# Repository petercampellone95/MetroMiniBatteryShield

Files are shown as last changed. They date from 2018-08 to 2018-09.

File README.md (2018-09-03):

# Metro Mini Battery Shield

## Summary
The Metro Mini Battery shield was designed as part of an introductory PCB design course with the primary goal of being the power source and power platform for several other shields (I.E. physically identical "daugther" boards) that would plug into it. 

The battery shield was designed with the following requirements/features in mind:

- Be able to supply approximately 1A of continuous current in order to power Metro Mini and up to three other “daughter” boards simultaneously
- Be able to charge an externally connected LiPo battery and still power the Metro Mini and up to three other “daughter” boards simultaneously
- Be able to take power in from either an external source or from the USB cable connected to the Metro Mini board
- Be able to switch between USB power and battery power automatically in the case that either one is not available
- Be able to measure current draw using a built-in current sense resistor
- Be able to set the charge rate in order to select different charge rates based on different power inputs (USB or external)
- Feature an On/Off switch in order to disable the charger completely if necessary
- The fuel gauge needs to be able to report battery statistics to the Metro Mini over I2C at a regular interval such that the tri-color LED can be used as a visual indication of the “fuel” level of the battery
- Feature a built-in 5V step-up regulator that can take a wide range of input voltage and output a constant 5V (primarily used for stepping up LiPo 3.7V to 5V)

The entire board was designed using Altium Circuitmaker which is a free,stripped down version of Altium Designer. While limited, the software was more than capable for our requirements.
After the design stage was completed the Gerber design files were sent to OSH Park where three copies of our board were fabricated along with a stencil from OSH Stencils. From here we assembled one complete board and began our testing the results of which you can find more about in the final project report. Overall though, the board operated as expected with only some minor design changes needed.

*Please see the ELE391 Final Project report for more specific technical details*

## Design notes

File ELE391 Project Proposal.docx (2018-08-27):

ELE 391 Project Proposal

Peter Campellone, Zackery Duclos, Cole Wright

2/8/2018

Project Focus: LiPo Battery Charger and Fuel Gauge with external battery connection

Project Summary: The overall goal of this project is to create a circuit capable of powering all four daughter-boards as well as the Metro Mini itself. Due to the size of the PCB being constrained to 1.7” x 0.7” we will not be able to integrate a battery into the PCB itself and instead will connect a LiPo battery externally using a JST connector. In order to charge the battery, we will be using a LiPO specific battery charger which also integrates some useful power management features. The primary concern that we previously faced was how to switch between USB charging, USB power, or battery power. The specific power management IC that we chose is able to automatically switch between these based on some parameters that we will later set. Now, in order to measure the remaining capacity of the battery we will be using a LiPO fuel gauge IC which is specifically designed to measure and report the status of a LiPO battery. This is advantageous to directly measuring the battery voltage and setting up a scale based on maximum and minimum values because LiPo battery voltages (at load) are not entirely linear curves. This fuel gauge IC communicates through I2C and by default will switch on an LED at a point where the LiPo battery is about to “die”. By adding some code to the provided code examples we will be able to have the fuel gauge IC switch on some LEDs to indicate different states in the charge/voltage level of the battery. Instead of being limited to exclusively when the battery is about to “die” we can also report when the battery is at optimal voltage levels and when the battery is below optimal levels but still providing power as expected.

In general, we expect to be able to produce a schematic and PCB with these capabilities and functions by the due date. More details about the specific parts and general function of the system can be found in the attached files.

Min Reqs:

-1700 x 700 mils x 62 mils thick

-80 mil radius rounded corners

-4 non-plated mounting holes, 75x75 mils from corners, 2.2mm dia, 0.125” standoff on each

-Pinout to match metro mini

-Envelope:

-0.400” stacking height

-0.280” top clearance

-0.100” bottom clearance

-Battery board output, VIN (6V+) (Current req. TBD per system)

-Current sense resistor on power rails (shunts) on bottom of board: CSR1206FTR100

-50 mil round test points (on bottom of board)

-Fiducial on tope side, 1mm pad, 0.5mm SM exp

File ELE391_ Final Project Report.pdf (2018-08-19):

## ELE391: Final Project Report - Metro Mini Battery Shield

### By: Peter Campellone, Zack Duclos, Cole Wright May 3, 2018

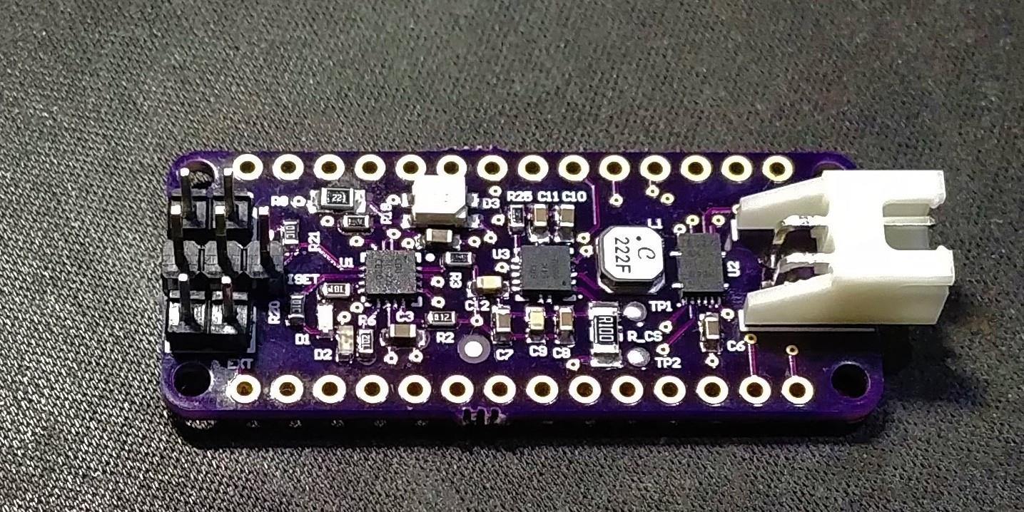
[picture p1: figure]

### Board Requirements

- Be able to supply approximately 1A of continuous current in order to power Metro Mini and up to three other “daughter” boards
- Be able to charge an externally connected LiPo battery
- Be able to charge an externally connected LiPo battery and still power the Metro Mini and up to three other “daughter” boards all at the same time
- Be able to take power in from either an external source or from the USB cable connected to the Metro Mini board
- Be able to switch between USB power and battery power automatically in the case that either one is not available
- Be able to measure current draw using a built-in current sense resistor
- Be able to set the charge rate in order to select different charge rates based on different power inputs (USB, external ,etc)
- Feature an On/Off switch in order to disable the charger completely if necessary
- The fuel gauge needs to be able to report battery statistics to the Metro Mini over I2C at a regular interval such that the tri-color LED can be used as a visual indication of the “fuel” level of the battery
- Feature an built-in 5V step-up regulator that can take a wide range of input voltage and output a constant 5V (primarily used for stepping up LiPo 3.7V to 5V)

### Implementation

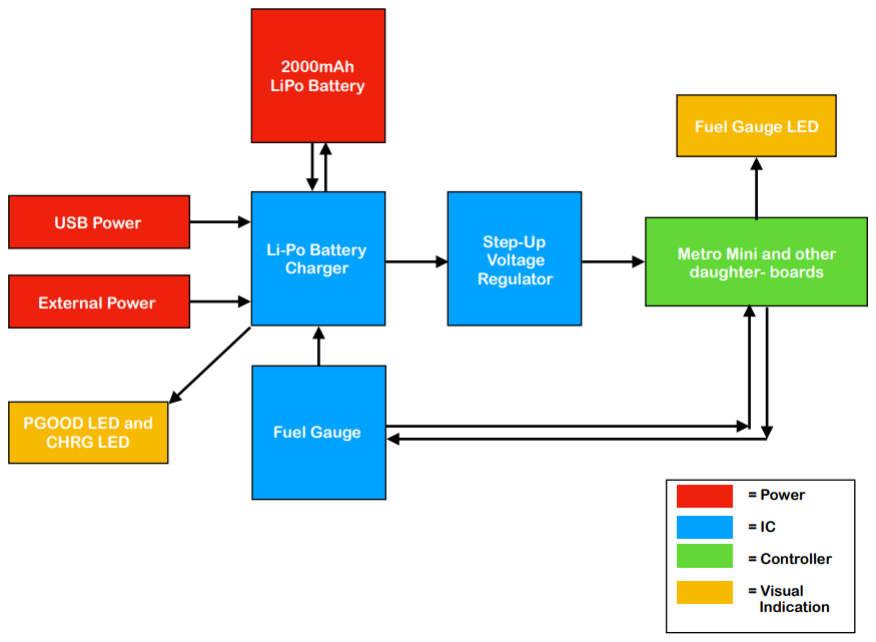
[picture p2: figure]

### The flowchart above displays the connections of the Metro Mini Battery Shield and how the different components interface with one another. The operation is described below:

### 1. Input power is either supplied by the USB connection on the Metro Mini or by an external power connection on the Battery Shield 2. From here the battery charger will direct that power depending on whether or not

a battery is connected.

a. If a battery IS connected then the battery charger will charge that battery and power the Metro Mini simultaneously using a built-in Texas Instruments feature called “Dynamic Power Path Management” b. If a battery IS NOT connected then the battery charger will directly route that power to the Metro Mini 3. Some considerations relevant to the charge and power management processes: a. The battery charger is only enabled when the PWR jumper is shorted b. External power input allowable range is 4.35 - 6.4V c. The ISET jumper defines the charge rate of the battery and connecting the jumper according to the table and image below will define the charge rate

Pin 1 | Pin 2 (GND) | Pin 3 | Charge Mode
Shorted | Shorted | Shorted | 100mA
Shorted | Shorted | Open | 500mA
Open | Shorted | Shorted | 972mA (max based on voltage regulator)
Open | Open | Open | Standby (default)

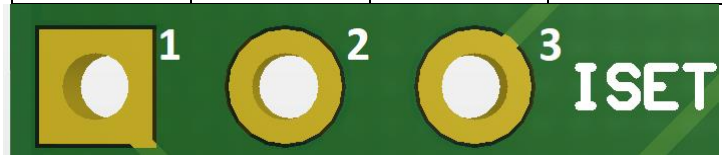
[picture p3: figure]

4. If the battery charging process is started and proceeding successfully then the CHRG LED will illuminate 5. If a battery is connected correctly and the battery charger has recognized it then the PGOOD LED will illuminate 6. The power that passes through the battery charger is sent to the Step-Up voltage regulator in order to output a constant +5V for use by the Metro Mini and other daughter boards. All power will be sent through the step-up regulator regardless

of the power input type or whether or not a battery is connected.

### 7. While all of this is happening the fuel gauge will directly measure the battery and multiple statistics relevant to the battery. These statistics are sent back to the Metro Mini over I2C using Arduino code that was written specifically to be used to

interface with the BQ27441 fuel gauge.

### 8. Part of the Arduino code will drive one of the LEDs on the tri-color LED based on the charge percentage of the battery (a.k.a. State of charge). The color of the LED is based on the following table and state of charge value:

State of Charge | LED Color
Less than 30% (inclusive) | Red
Between 30% and 70% | Yellow
Greater than 70% (inclusive) | Green

### Testing Performed

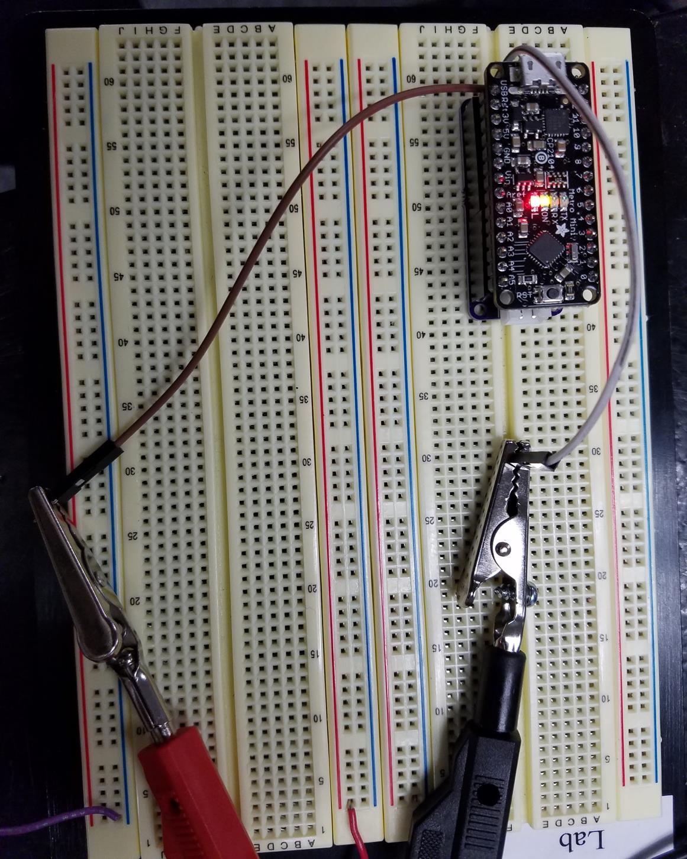
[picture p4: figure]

Figure 1: Testing PCB with external power input, successfully powering Metro Mini

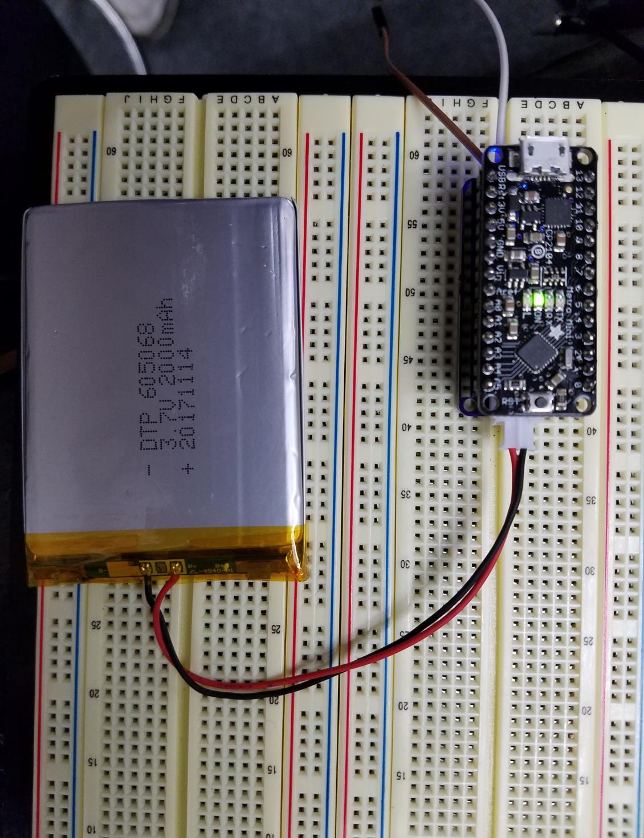
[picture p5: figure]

Figure 2: Testing PCB with battery power, successfully powering Metro Mini, PGOOD LED illuminated indicated battery is recognized by battery charger

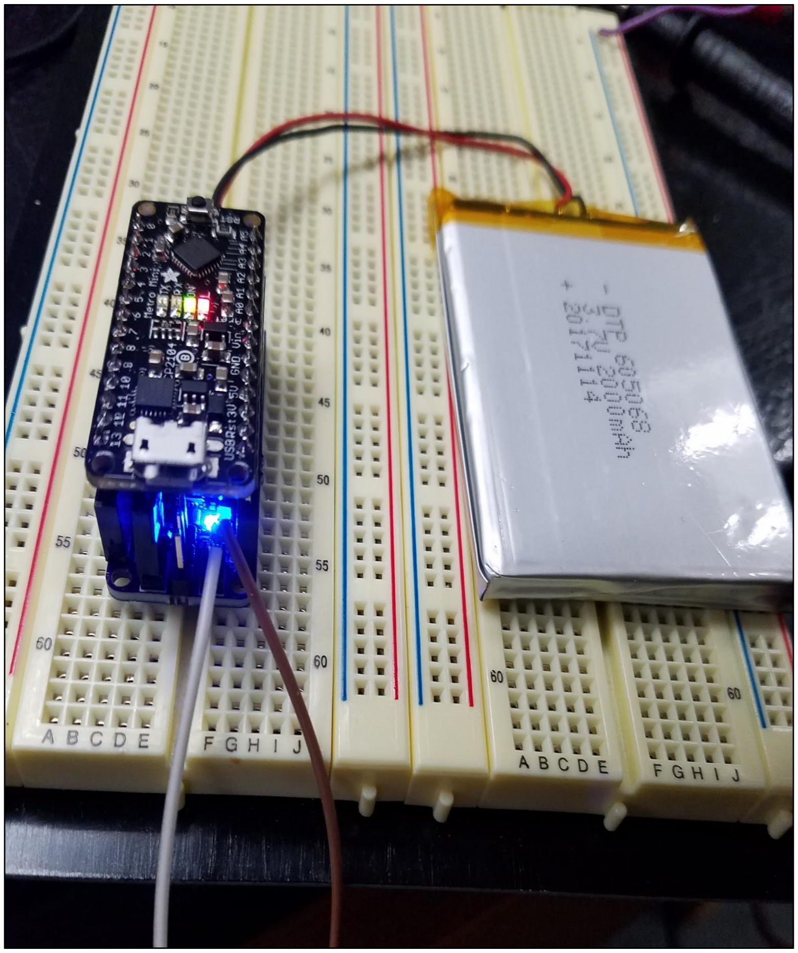
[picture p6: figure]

Figure 3: Testing PCB with battery power, successfully powering Metro Mini, PGOOD LED illuminated indicating that battery charger has recognized battery

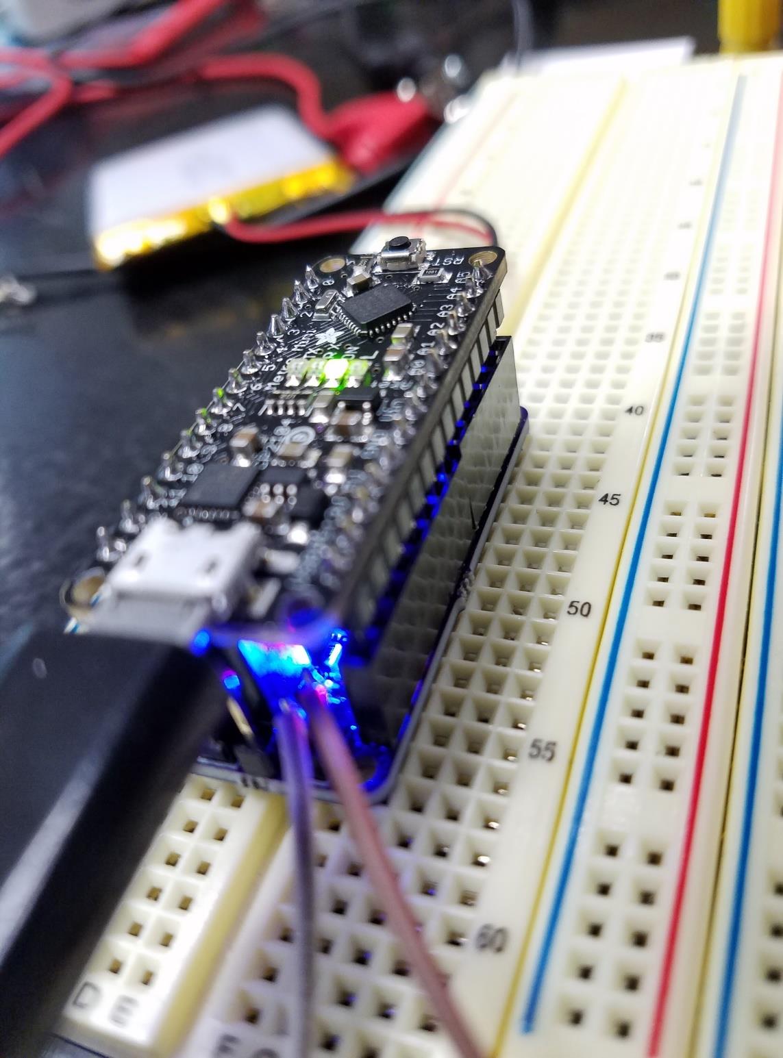
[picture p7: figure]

Figure 4: Testing PCB with USB connection, successfully powering Metro Mini, PGOOD LED illuminated indicating that battery charger has recognized battery, CHRG LED illuminated indicating that battery is being charged using USB power

*In each test, the PCB was tested with all four of the charge rate settings to verify operation and expected current draw*

### Conclusion

In reference to the board requirements listed above only one part of the entire PCB did not work. Specifically, the tri-color LED used as a visual indication of the fuel level did not work after assembly. After examining the PCB, schematics, and datasheet it was determined that the tri-color LED was
common anode although it had been connected as if it was common cathode. This caused the LED to be reversed bias and therefore not illuminate. In order to fix this the ground connection to the common anode pin on the LED needed to be replaced with a connection to the +5V rail. Further, the initial design featured three digital pins on the Metro Mini’s Atmega328 to be used in order to source current to power each of the individual LEDs although with the incorrect common anode connection driving current from the digital pins would not complete the circuit. After our initial testing we tried cutting a trace to ground from the resistor in the tri-color LED circuit and then wiring in a jumper wire to a 5V bus in order to source current through the digital pins for each LED to complete the circuit. While this did work, the solution was not ideal and the modifications were revered to normal in order prevent the PCB from becoming non-functional or damaged.

Regardless of this non-functioning part of the circuit, the rest of the PCB did function as expected. The PCB did meet all of the other board requirements as mentioned above. Although, there were a number of errors noticed and subsequent solutions that could be made in a second revision of the board. These errors and their corresponding solutions are listed below:

### Error/Solution Log

Error: Tri-Color LED wired as common cathode instead of common anode.
Solution: Replace GND connection to tri-color LED anode with +5V bus connection

Error: Jumpers for PWR, EXT, and ISET are difficult to access when Metro Mini is installed on top Solution: Replace Jumpers with right angle connectors or something easily accessible from side or bottom

Error: CHG and PGOOD LED silkscreens are reversed
Solution: Change net labels in schematic

Error: Adjust resistor value for PGOOD LED
Solution: Re-calculate resistor value for PGOOD LED (red) or replace with a different color LED to have comparable brightness to CHRG (blue) LED

Error: Resistor value on tri-color LED is too large and LED brightness is too low
Solution: Replace with a new resistor, recalculate optimal value (likely 100-120 ohm)

Error: JST Connector is wrong physical size, pins are too big for battery connector
Solution: Replace JST connector with correct female part to match physical size and pin size of male JST battery connector

Error: JST connector does not sit flat on PCB and is easily bent when inserting battery connector
Solution: Replace with JST connector with different physical design that sits more securely and fits better on the board

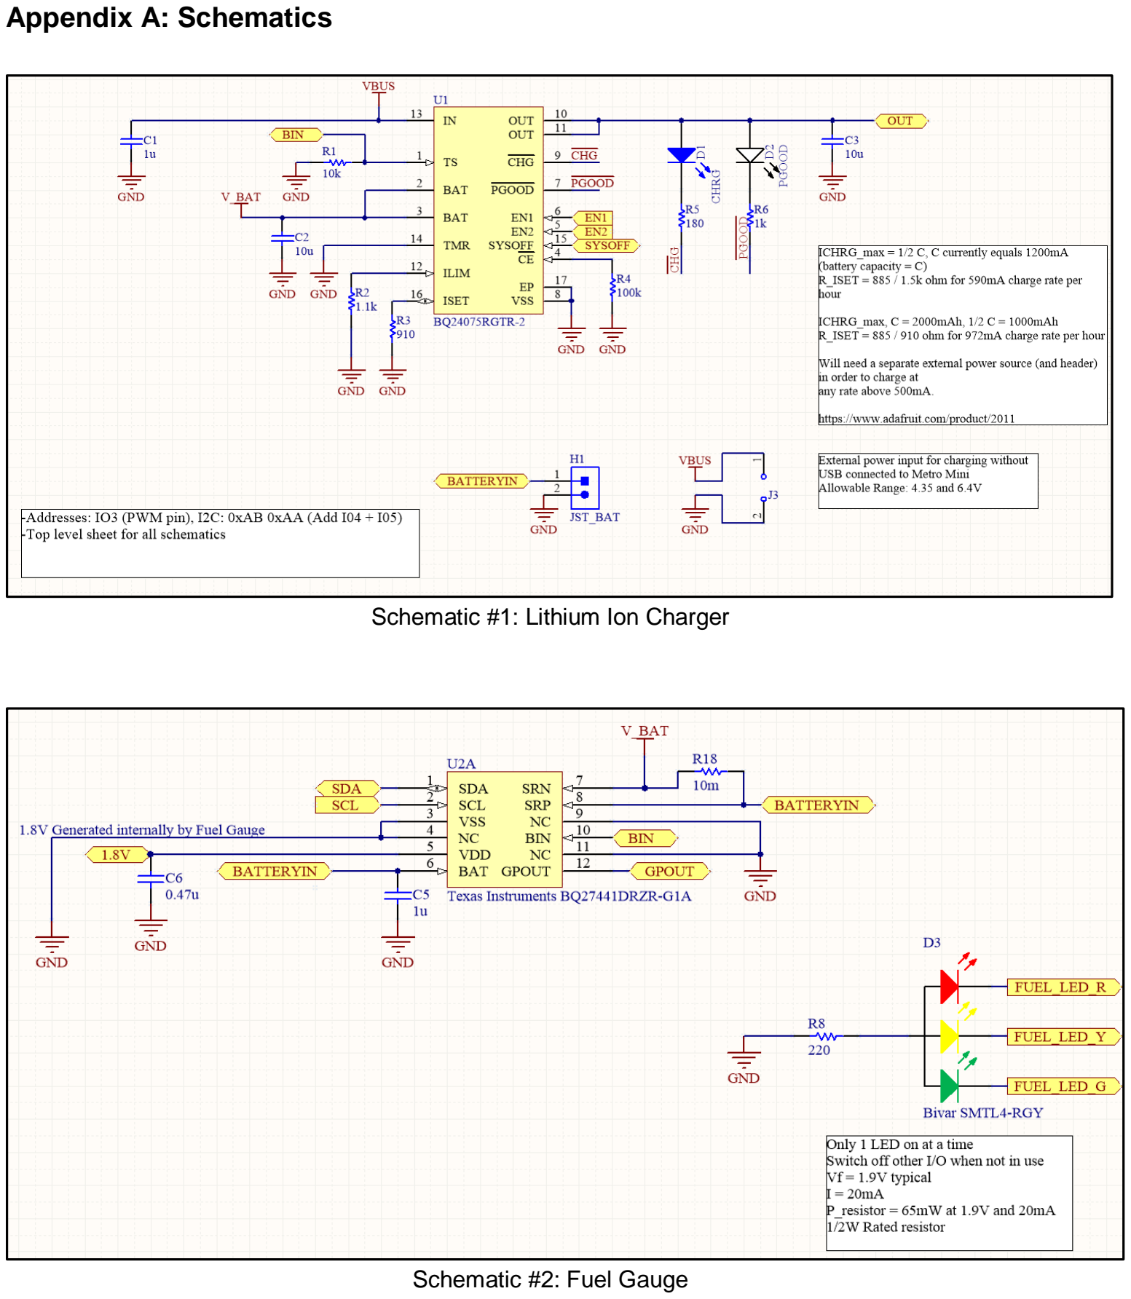
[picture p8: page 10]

### Appendix A: Schematics

Schematic #1: Lithium Ion Charger

Schematic #2: Fuel Gauge

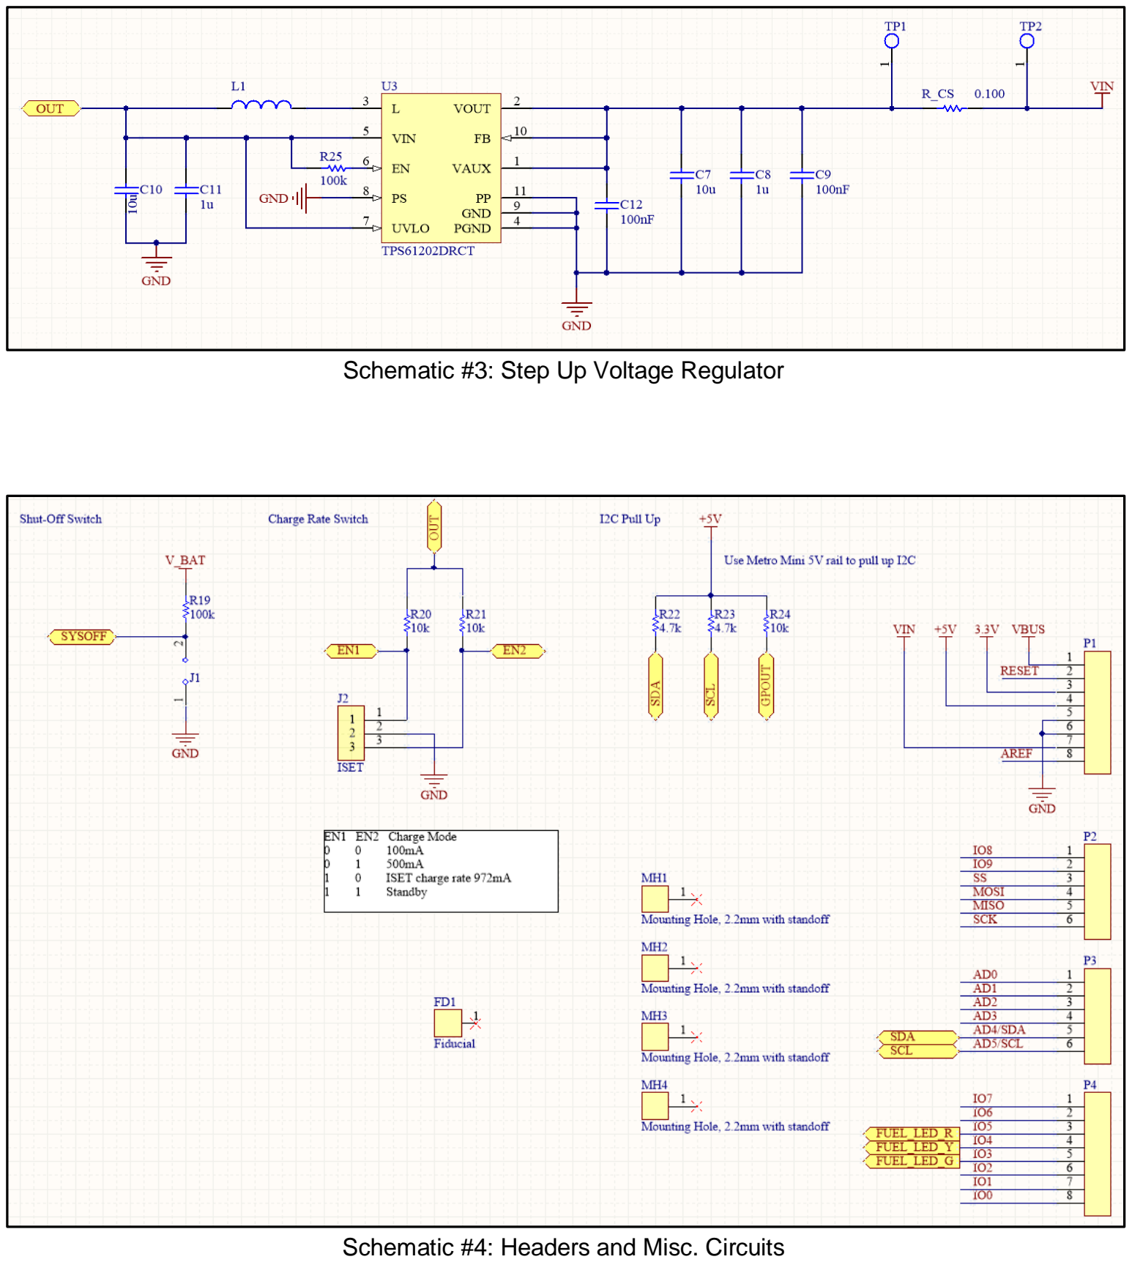
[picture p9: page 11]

Schematic #3: Step Up Voltage Regulator

Schematic #4: Headers and Misc. Circuits

### Appendix B: Arduino Code

/****************************************************************************** BQ27441_Basic
BQ27441 Library Basic Example
Jim Lindblom @ SparkFun Electronics
May 9, 2016
https://github.com/sparkfun/SparkFun_BQ27441_Arduino_Library

Modified by: Peter Campellone, University of Rhode Island
April 20, 2018

Demonstrates how to set up the BQ27441 and read state-of-charge (soc), battery voltage, average current, remaining capacity, average power, and state-of-health (soh).
******************************************************************************/ #include <SparkFunBQ27441.h>

// Set BATTERY_CAPACITY to the design capacity of your battery. const unsigned int BATTERY_CAPACITY = 2000; // e.g. 2000mAh battery

void setup()
{
pinMode(3, OUTPUT); //Setup pin #3, green LED, as output for sourcing current pinMode(4, OUTPUT); //Setup pin #4, yellow LED, as output for sourcing current pinMode(5, OUTPUT); //Setup pin #5, red LED, as output for sourcing current

Serial.begin(115200); //Start serial monitor at 115200 bps
setupBQ27441(); //Connect BQ27441
}

void loop()
{
int stateOfCharge = printBatteryStats(); //Print battery stats to serial monitor and return SOC for use with //LEDGauge()
//int stateOfCharge = 85; //for testing led directly
LEDGauge(stateOfCharge); //Displays SOC using tri-color LED
delay(1000); //Updates every 1s
}

void setupBQ27441(void)
{
// Use lipo.begin() to initialize the BQ27441-G1A and confirm that it's // connected and communicating.
if (!lipo.begin()) // begin() will return true if communication is successful {
// If communication fails, print an error message and loop forever. Serial.println("Error: Unable to communicate with BQ27441."); Serial.println("Check wiring and try again."); Serial.println("Battery must be plugged in for fuel gauge to work!"); while (1) ;
}
Serial.println("Connected to BQ27441!");

// Uset lipo.setCapacity(BATTERY_CAPACITY) to set the design capacity // of your battery.
lipo.setCapacity(BATTERY_CAPACITY);
}

int printBatteryStats()
{
// Read battery stats from the BQ27441-G1A
unsigned int soc = lipo.soc(); // Read state-of-charge (%)
unsigned int volts = lipo.voltage(); // Read battery voltage (mV)
int current = lipo.current(AVG); // Read average current (mA)
unsigned int fullCapacity = lipo.capacity(FULL); // Read full capacity (mAh) unsigned int capacity = lipo.capacity(REMAIN); // Read remaining capacity (mAh) int power = lipo.power(); // Read average power draw (mW)
int health = lipo.soh(); // Read state-of-health (%)

// Now print out those values:
String toPrint = String(soc) + "% | ";
toPrint += String(volts) + " mV | ";
toPrint += String(current) + " mA | ";
toPrint += String(capacity) + " / ";
toPrint += String(fullCapacity) + " mAh | ";
toPrint += String(power) + " mW | ";
toPrint += String(health) + "%";

Serial.println(toPrint);

return soc;
}

void LEDGauge(int stateOfCharge) //Displays charge state using tri-color LED, //SOC < 30%: Red, 30% < SOC < 70%: Yellow, SOC >= 70%: Green {
if(stateOfCharge <= 30){
digitalWrite(3,LOW); //Turn off Green digitalWrite(4,LOW); //Turn off Yellow digitalWrite(5,HIGH); //Turn on Red

} else if (stateOfCharge > 30 and stateOfCharge < 70){ digitalWrite(3,LOW); //Turn off Green digitalWrite(4,HIGH); //Turn on Yellow digitalWrite(5,LOW); //Turn off Red

} else if (stateOfCharge >= 70){ digitalWrite(3,HIGH); //Turn on Green digitalWrite(4,LOW); //Turn off Yellow digitalWrite(5,LOW); //Turn off Red

} else
Serial.println("ERROR: State of charge outside range (0-100)");

}

void LEDBoot() //Run on boot to test tri-color LED, for use when tri-color LED is wired correctly {
for(int i = 0; i++; i <=20) //Total runtime ~= 50ms * 3 * 10 = 1.5s
{
digitalWrite(3,LOW); //Turn off Green
digitalWrite(4,LOW); //Turn off Yellow
digitalWrite(5,HIGH); //Turn on Red delay(50); //Delay

digitalWrite(3,LOW); //Turn off Green digitalWrite(4,HIGH); //Turn off Yellow digitalWrite(5,LOW); //Turn on Red delay(50); //Delay //

digitalWrite(3,HIGH); //Turn off Green digitalWrite(4,LOW); //Turn off Yellow digitalWrite(5,LOW); //Turn on Red delay(50); //Delay
}
}

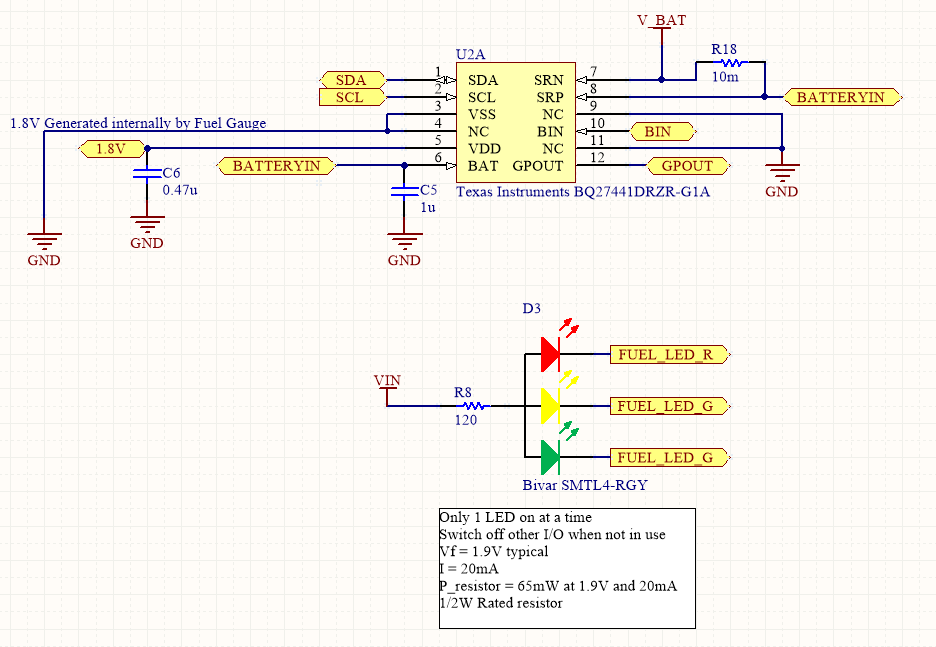
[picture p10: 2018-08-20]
Schematics/FuelGauge_Schematic.PNG

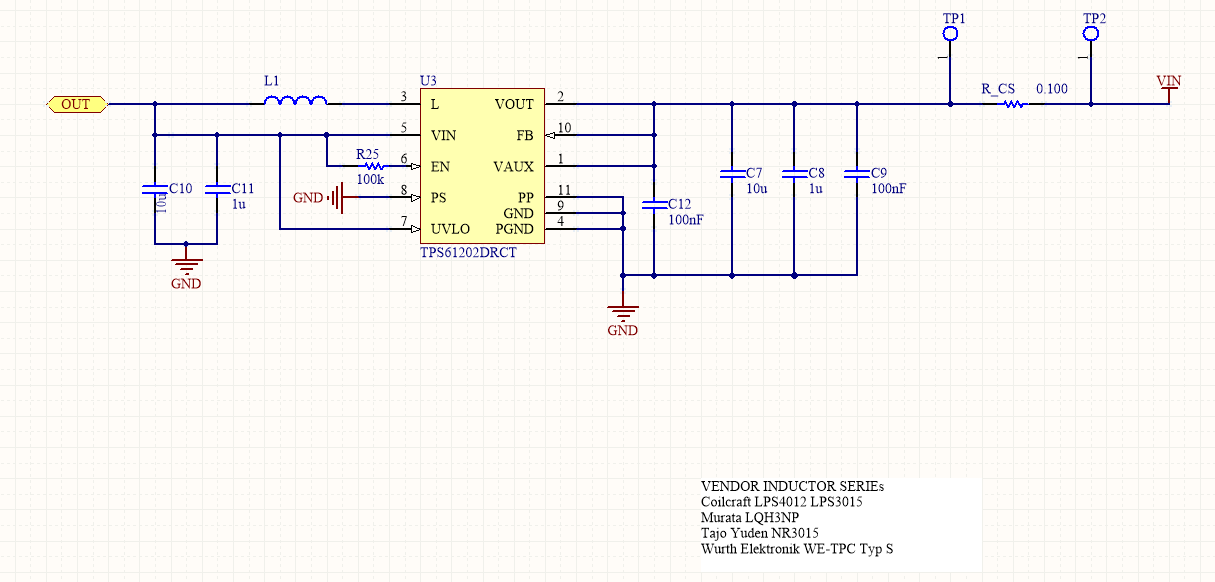
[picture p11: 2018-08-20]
Schematics/Vreg_Schematic.PNG

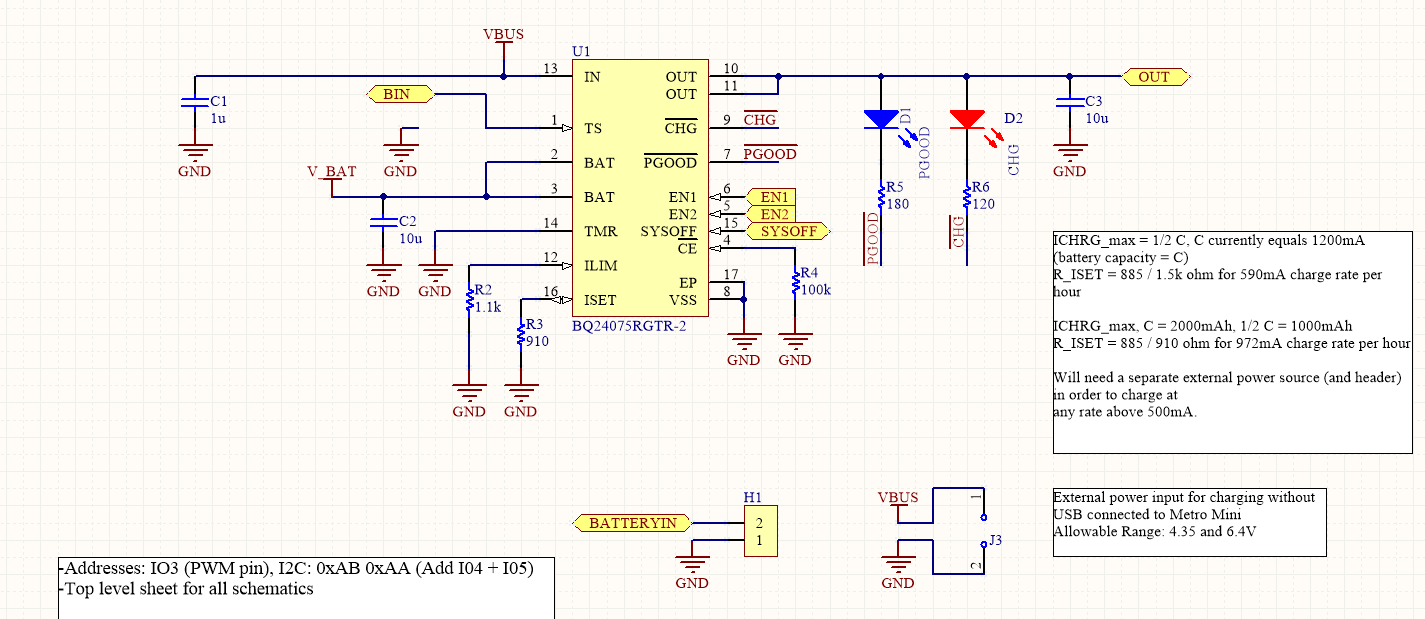
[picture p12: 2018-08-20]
Schematics/LiIonCharger_Schematic.PNG

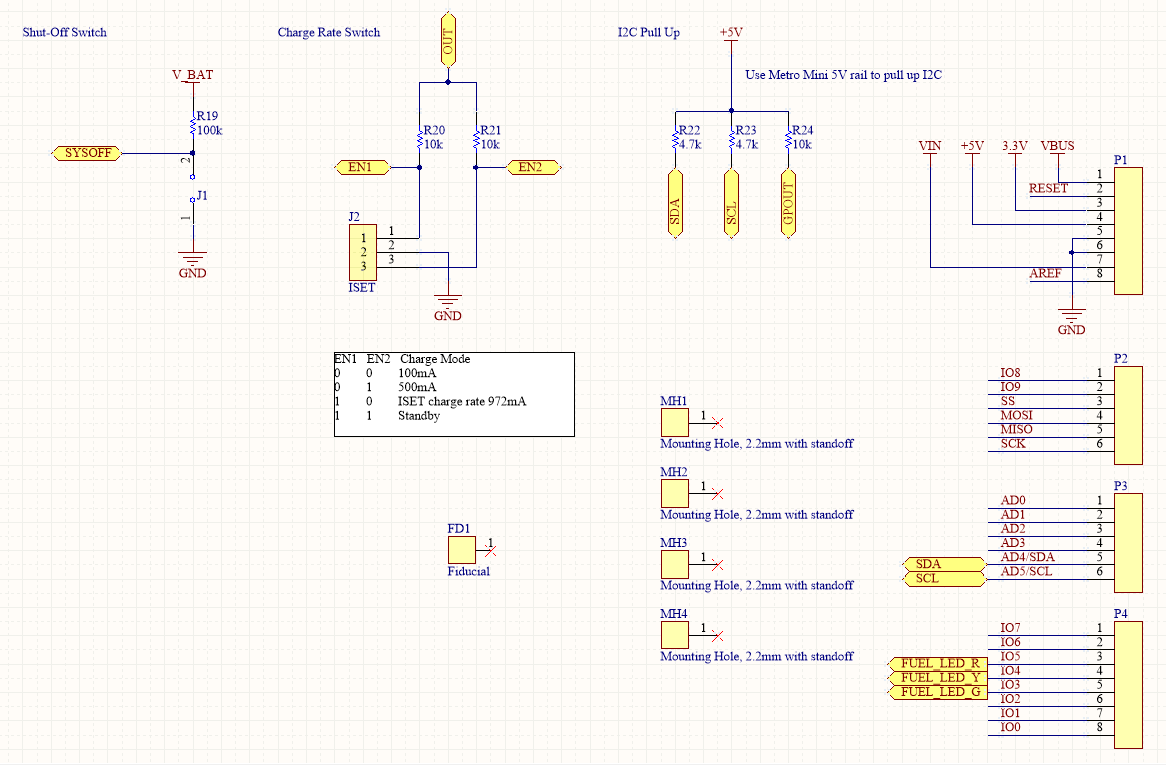
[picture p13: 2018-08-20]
Schematics/Headers_Schematic.PNG

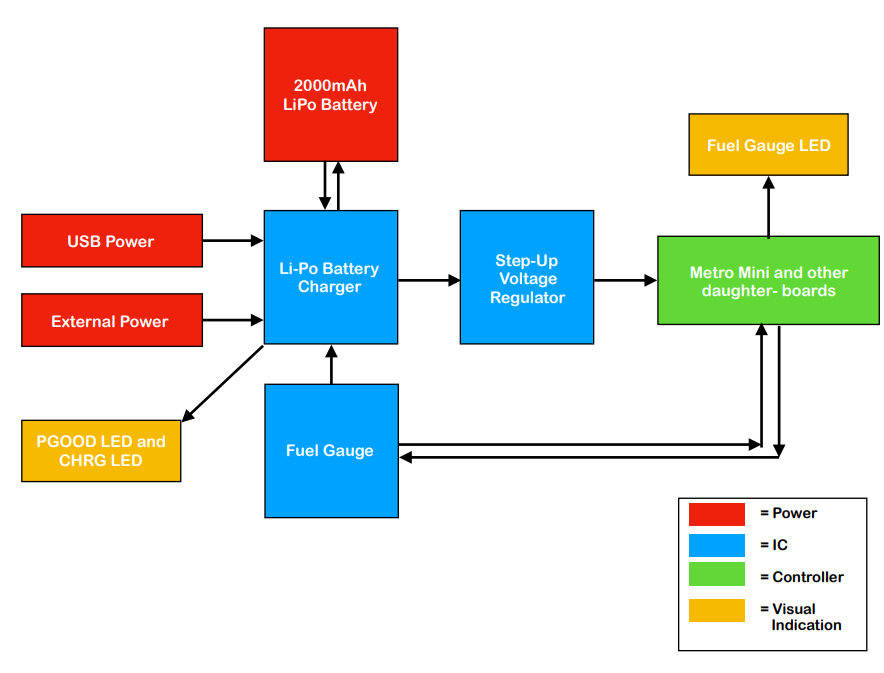
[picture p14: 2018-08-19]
ELE391-Final_Flowchart.PNG

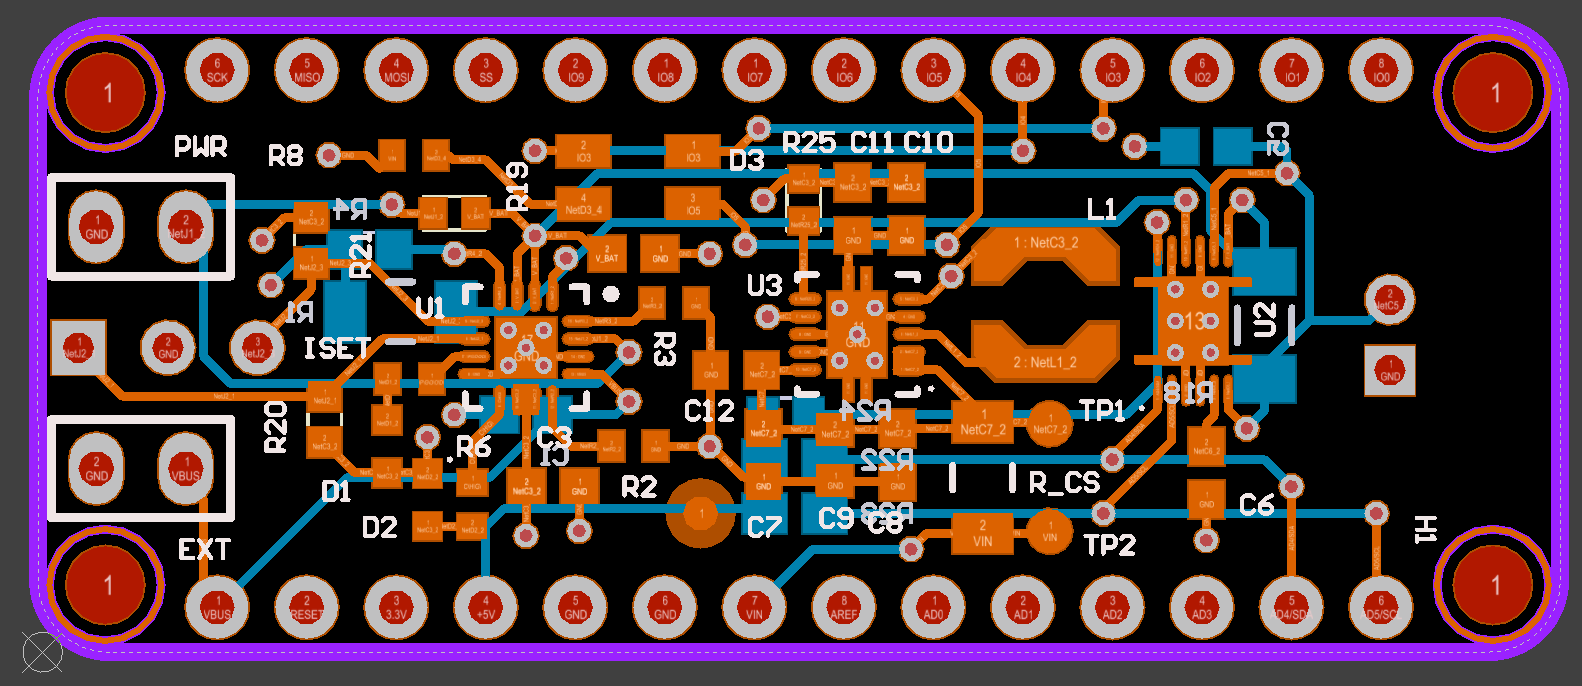
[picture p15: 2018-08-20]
Board Images-Renders/Top+BottomLayer.PNG

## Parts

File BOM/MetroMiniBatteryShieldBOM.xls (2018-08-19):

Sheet: BOM Report
Bill of Materials |  | Metro Mini Battery Shield - ELE391 Project
Source Data From: |  | MetroMiniBatteryShield.PrjPcb
Project: |  | MetroMiniBatteryShield.PrjPcb
Variant: |  | None
Creation Date: | 3/28/2018 | 8:54:14 PM
Print Date: | 2018-03-28 | 21:06:00
Comment | Designator | Description | Quantity
1u 0603 SMD Cap | C1, C5, C8, C11 | C Series 0603 1 uF 10 V ±10 % Tolerance X5R SMT Multilayer Ceramic Capacitor | 4
10u 0603 SMD Cap | C2, C3, C7, C10 | Multilayer Ceramic Capacitor, C Series, 10 - F, - 10%, X5R, 10 V, 0603 [1608 Metric] | 4
0.47u 0603 SMD Cap | C6 | C Series 0603 0.47 uF 50 V ±10 % Tolerance X7R SMT Multilayer Ceramic Capacitor | 1
100nF 0603 SMD Cap | C9, C12 | 0603 0.1 uF 25 V ±10 % Tolerance X7R Surface Mount Multilayer Ceramic Capacitor | 2
CHRG 0603 SMD LED | D1 | Blue 130° Water Clear 605 nm 60 mcd 2 V LED Chip SMT (1.6 x 0.8 mm) | 1
PGOOD 0603 SMD LED | D2 | TLMS1100-GS08 White LED, 639 nm 1608 (0603), Rectangle Lens SMD package | 1
Bivar SMTL4-RGY Tri-Color LED | D3 | LED, SMD, PLCC4, Tri-Color, Red (640nm, 36mcd) / Green (570nm, 40mcd) / Yellow ( | 1
Fiducial | FD1 | 1mm fiducial with 0.5mm SM clearance | 1
JST_BAT Connector | H1 | Male Header, Pitch 2.5 mm, 1 x 2 Position, Height 6.1 mm, Tail Length 3.4 mm, -25 to 85 degC, RoHS, Bulk | 1
PWR 2 pos Header | J1 | Conn Unshrouded Header PL 2 POS 2.54mm Solder ST Thru-Hole | 1
ISET 3pos Header | J2 | Board-To-Board Connector, Vertical, WR-PHD Series, Through Hole, Header, 3, 2.54 mm | 1
EXT 2pos Header | J3 | Conn Unshrouded Header PL 2 POS 2.54mm Solder ST Thru-Hole | 1
Coilcraft LPS4012-222MRB | L1 | COILCRAFT LPS4012-222MRB INDUCTOR, SHLD, 2.2UH, 20%, 1.2A, SMD | 1
Mounting Hole, 2.2mm with standoff | MH1, MH2, MH3, MH4 | NPTH Mounting Hole with 0.400" Bivar 937-400 Standoff | 4
Samtec ESQ-108-24-T-S | P1, P4 | Conn Elevated Socket SKT 8 POS 2.54mm Solder ST Thru-Hole Tube | 2
Samtec ESQ-106-24-T-S | P2, P3 | Conn Elevated Socket SKT 6 POS 2.54mm Solder ST Thru-Hole Tube | 2
Stackpole Electronics CSR1206FTR100 | R_CS | Res Thick Film 1206 0.1 Ohm 1% 0.5W(1/2W) ??? }100ppm/ Molded SMD Paper T/R | 1
10k SMD 0603 Res | R1 | Surface Mount Chip Resistor, Thin Film, RT Series, 10 kohm, 100 mW, 1%, 75 V, 0603 [1608 Metric] | 1
10m SMD 1206 Res | R18 | Res Thick Film 1206 0.1 Ohm 1% 0.5W(1/2W) ??? }100ppm | 1
100k SMD 0603 Res | R19, R25 | Res Thick Film 1.6 x 0.8 mm 100K Ohm 1% 0.1W(1/10W) 100ppm/ C Molded SMD Punched Carrier T/R | 2
1.1k SMD 0603 Res | R2 | Thick Film Resistors - SMD 0603 1.1Kohms 5% Tol | 1
10k SMD 0603 Res | R20, R21, R24 | Resistor Thick Film 0603 10k Ohm 1% 1/10 Watt ±100ppm °C Surface Mount Punched Carrier Tape and Reel | 3
4.7k SMD 0603 Res | R22, R23 | RES SMD 4.7K OHM 5% 1/10W 0603 | 2
910 SMD 0603 Res | R3 | Thick Film Resistors - SMD 0603 910ohms 1% Tol | 1
100k SMD 0603 Res | R4 | Res Thick Film 1.6 x 0.8 mm 100K Ohm 1% 0.1W(1/10W) 100ppm/ C Molded SMD Punched Carrier T/R | 1
180 SMD 0603 Res | R5 | Thick Film Resistors - SMD 0603 180ohms 5% Tol | 1
1k SMD 0603 Res | R6 | Thick Film Resistors - SMD 0603 1Kohms 5% Tol | 1
220 SMD 0805 Res | R8 | Thick Film Resistors - SMD 0805 220ohms 5% Thick Film Resistor | 1
Testpoint, 50 mil round | TP1, TP2 | Testpoint, 50 mil round surface pad | 2
BQ24075RGTR-2 | U1 | USB-Friendly Li-Ion Battery Charger and Power-Path Management IC, Vout 5.5 V, 4.3 V, -40 to 85 degC, 16-pin QFN (RGT), Green (RoHS & no Sb/Br) | 1
Texas Instruments BQ27441DRZR-G1A | U2 | System-Side Impedance Track? Battery Fuel (Gas) Gauge 12-SON -40 to 85 | 1
TPS61202DRCT | U3 | Boost Voltage Converter with 0.3 to 5.5 V Input and 5 V Output, -40 to 85 degC, 10-Pin SON (DRC), Green (RoHS & no Sb/Br) | 1
 |  |  |  | 49
Approved |  | Notes

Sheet: Project Information
Project Full Path | C:\ProgramData\Altium\CircuitMaker {20690677-D4FD-4CB7-A4E9-00349D86A8F9}\Projects\354A3A29-DB29-4F35-BFF8-C48B12B8DA4F\7d7ec262-dcb9-4093-8c8e-15eefee6898d\MetroMiniBatteryShield.PrjPcb
Project Filename | MetroMiniBatteryShield.PrjPcb
Variant Name | None
Data-Source Filename | MetroMiniBatteryShield.PrjPcb
Data-Source Full Path | C:\ProgramData\Altium\CircuitMaker {20690677-D4FD-4CB7-A4E9-00349D86A8F9}\Projects\354A3A29-DB29-4F35-BFF8-C48B12B8DA4F\7d7ec262-dcb9-4093-8c8e-15eefee6898d\MetroMiniBatteryShield.PrjPcb
Title | FuelGauge - ELE391 Project
Total Quantity | 49
Report Time | 8:54:14 PM
Report Date | 3/28/2018
Report Date & Tine | 3/28/2018 8:54:14 PM
Output Name | BOM_PartType
Output Type | BOM_PartType
Output Generator Name | BOM
Output Generator Description | Bill of Materials
